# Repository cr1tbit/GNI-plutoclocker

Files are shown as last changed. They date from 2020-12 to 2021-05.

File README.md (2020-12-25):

# GNI-plutoclocker

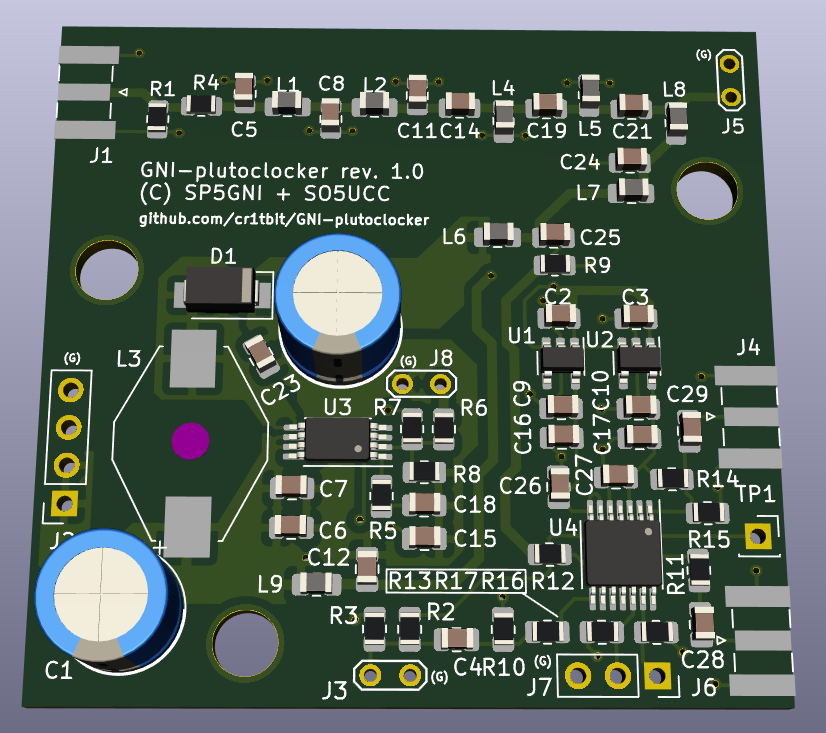
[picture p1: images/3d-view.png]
Board 3d view


This device serves a couple of roles:
* allowing clocking adalm-pluto by an external clock source of broad frequency range
* injecting clock signal into RF trace, for clocking modded LNB
* supplying LNB with DC voltage (12v/18v selectable with an external switch)
* additional clock output

The device is based on CDCE913 which is a neat 3-output clock source generator. It has an excillent, low jitter PLL inside, and has been tested to work well with an OCXO for the purpose of communication via OSCAR-100 satellite.

## Configuration

The device is programmed via I2C rail. The proper register values may be programmed, using an arduino sketch ( available in this repo).

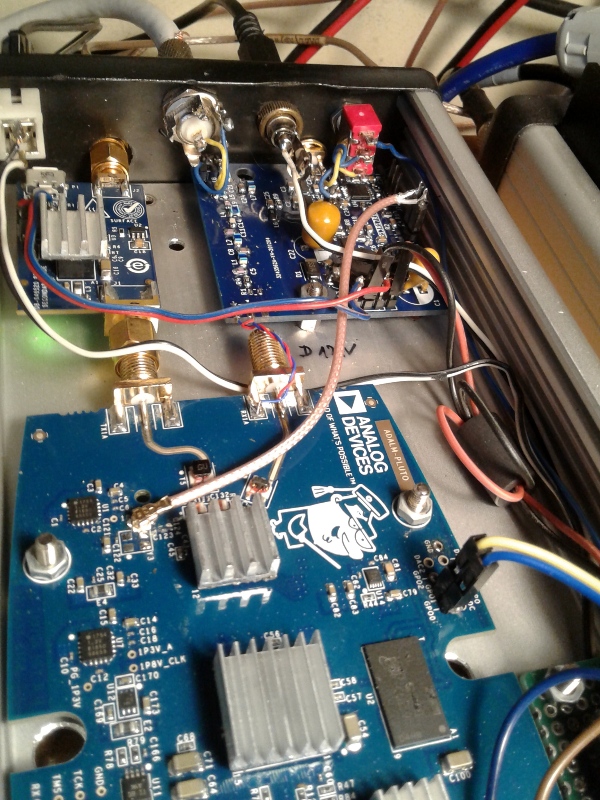
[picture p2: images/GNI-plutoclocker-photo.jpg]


More about this project may be found on https://hf5l.pl/en/adalm-pluto-clocker-2/

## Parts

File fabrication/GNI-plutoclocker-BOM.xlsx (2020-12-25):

Ref | Qnty | Value | Footprint
C1; | 1 | 100u/16V tantalum | Capacitor_THT:CP_Radial_D8.0mm_P3.80mm
C2; C3; C6; C16; C17; | 5 | 10u | Capacitor_SMD:C_0805_2012Metric
C4; C25; C28; C29; | 4 | 10n | Capacitor_SMD:C_0805_2012Metric
C5; C11; | 2 | 5p6 | Capacitor_SMD:C_0805_2012Metric
C7; | 1 | 1u | Capacitor_SMD:C_0805_2012Metric
C8; | 1 | 8p2 | Capacitor_SMD:C_0805_2012Metric
C9; C10; C12; C15; C23; C26; C27; | 7 | 100n | Capacitor_SMD:C_0805_2012Metric
C14; C21; | 2 | 2p7 | Capacitor_SMD:C_0805_2012Metric
C18; | 1 | 1n | Capacitor_SMD:C_0805_2012Metric
C19; | 1 | 1p2 | Capacitor_SMD:C_0805_2012Metric
C22; | 1 | 22u/25v tantalum | Capacitor_THT:CP_Radial_D8.0mm_P3.80mm
C24; | 1 | 68p | Capacitor_SMD:C_0805_2012Metric
D1; | 1 | D_Schottky 20V/1A | Diode_SMD:D_SMA
J1; | 1 | PLUTO_RF_IN | Connector_Coaxial:SMA_EdgeMount male
J2; | 1 | PLUTO_5V | Connector_PinSocket_1x04_P2.54mm_Vertical
J4; | 1 | 10MHZ_IN | Connector_Coaxial:SMA_EdgeMount female
J7; | 1 | I2C_PROG | Connector_PinSocket_1x03_P2.54mm_Vertical
J8; | 1 | 18V_ENA | Connector_PinSocket_1x02_P2.54mm_Vertical
L1; L2; | 2 | 15nH | Inductor_SMD:L_0805_2012Metric_Pad1.15x1.40mm
L3; | 1 | 6.8uH | Inductor_SMD:L_Fastron_PISN_Handsoldering
L4; L5; | 2 | 10nH | Inductor_SMD:L_0805_2012Metric_Pad1.15x1.40mm
L6; L9; | 2 | 2.2uH | Inductor_SMD:L_0805_2012Metric_Pad1.15x1.40mm
L7; L8; | 2 | 100nH | Inductor_SMD:L_0805_2012Metric_Pad1.15x1.40mm
R1; | 1 | 68 | Resistor_SMD:R_0805_2012Metric
R2; R3; R16; R17; | 4 | DNP | Resistor_SMD:R_0805_2012Metric
R4; | 1 | 220 | Resistor_SMD:R_0805_2012Metric
R5; R6; | 2 | 56k | Resistor_SMD:R_0805_2012Metric
R7; | 1 | 240k | Resistor_SMD:R_0805_2012Metric
R8; | 1 | 27k | Resistor_SMD:R_0805_2012Metric
R9; R10; | 2 | 100 | Resistor_SMD:R_0805_2012Metric
R11; R12; R13; | 3 | 22 | Resistor_SMD:R_0805_2012Metric
R14; R15; | 2 | 1k | Resistor_SMD:R_0805_2012Metric
U1; | 1 | MIC5504-3.3YM5 | Package_TO_SOT_SMD:SOT-23-5
U2; | 1 | MIC5504-1.8YM5 | Package_TO_SOT_SMD:SOT-23-5
U3; | 1 | TPS61085 | Package_SO:TSSOP-8_4.4x3mm_P0.65mm
U4; | 1 | CDCE913 | Package_SO:TSSOP-14_4.4x5mm_P0.65mm

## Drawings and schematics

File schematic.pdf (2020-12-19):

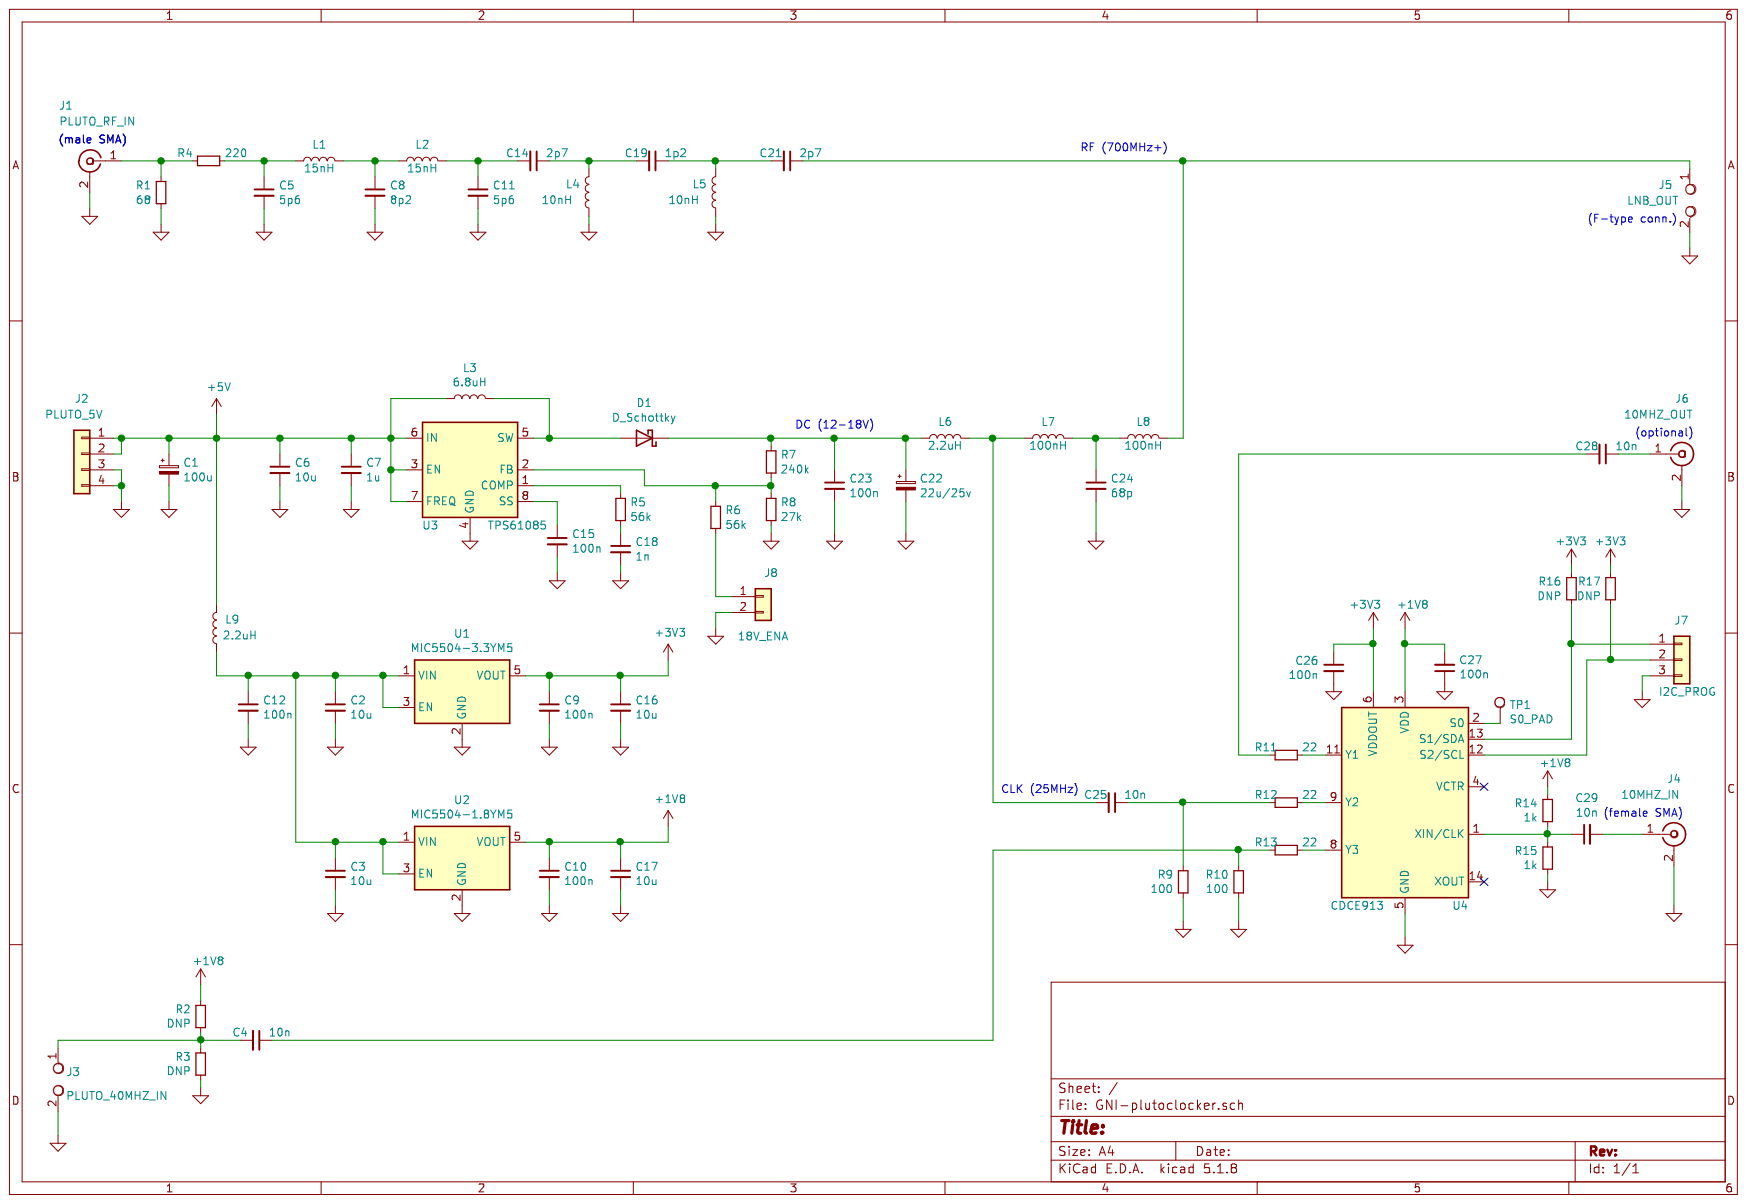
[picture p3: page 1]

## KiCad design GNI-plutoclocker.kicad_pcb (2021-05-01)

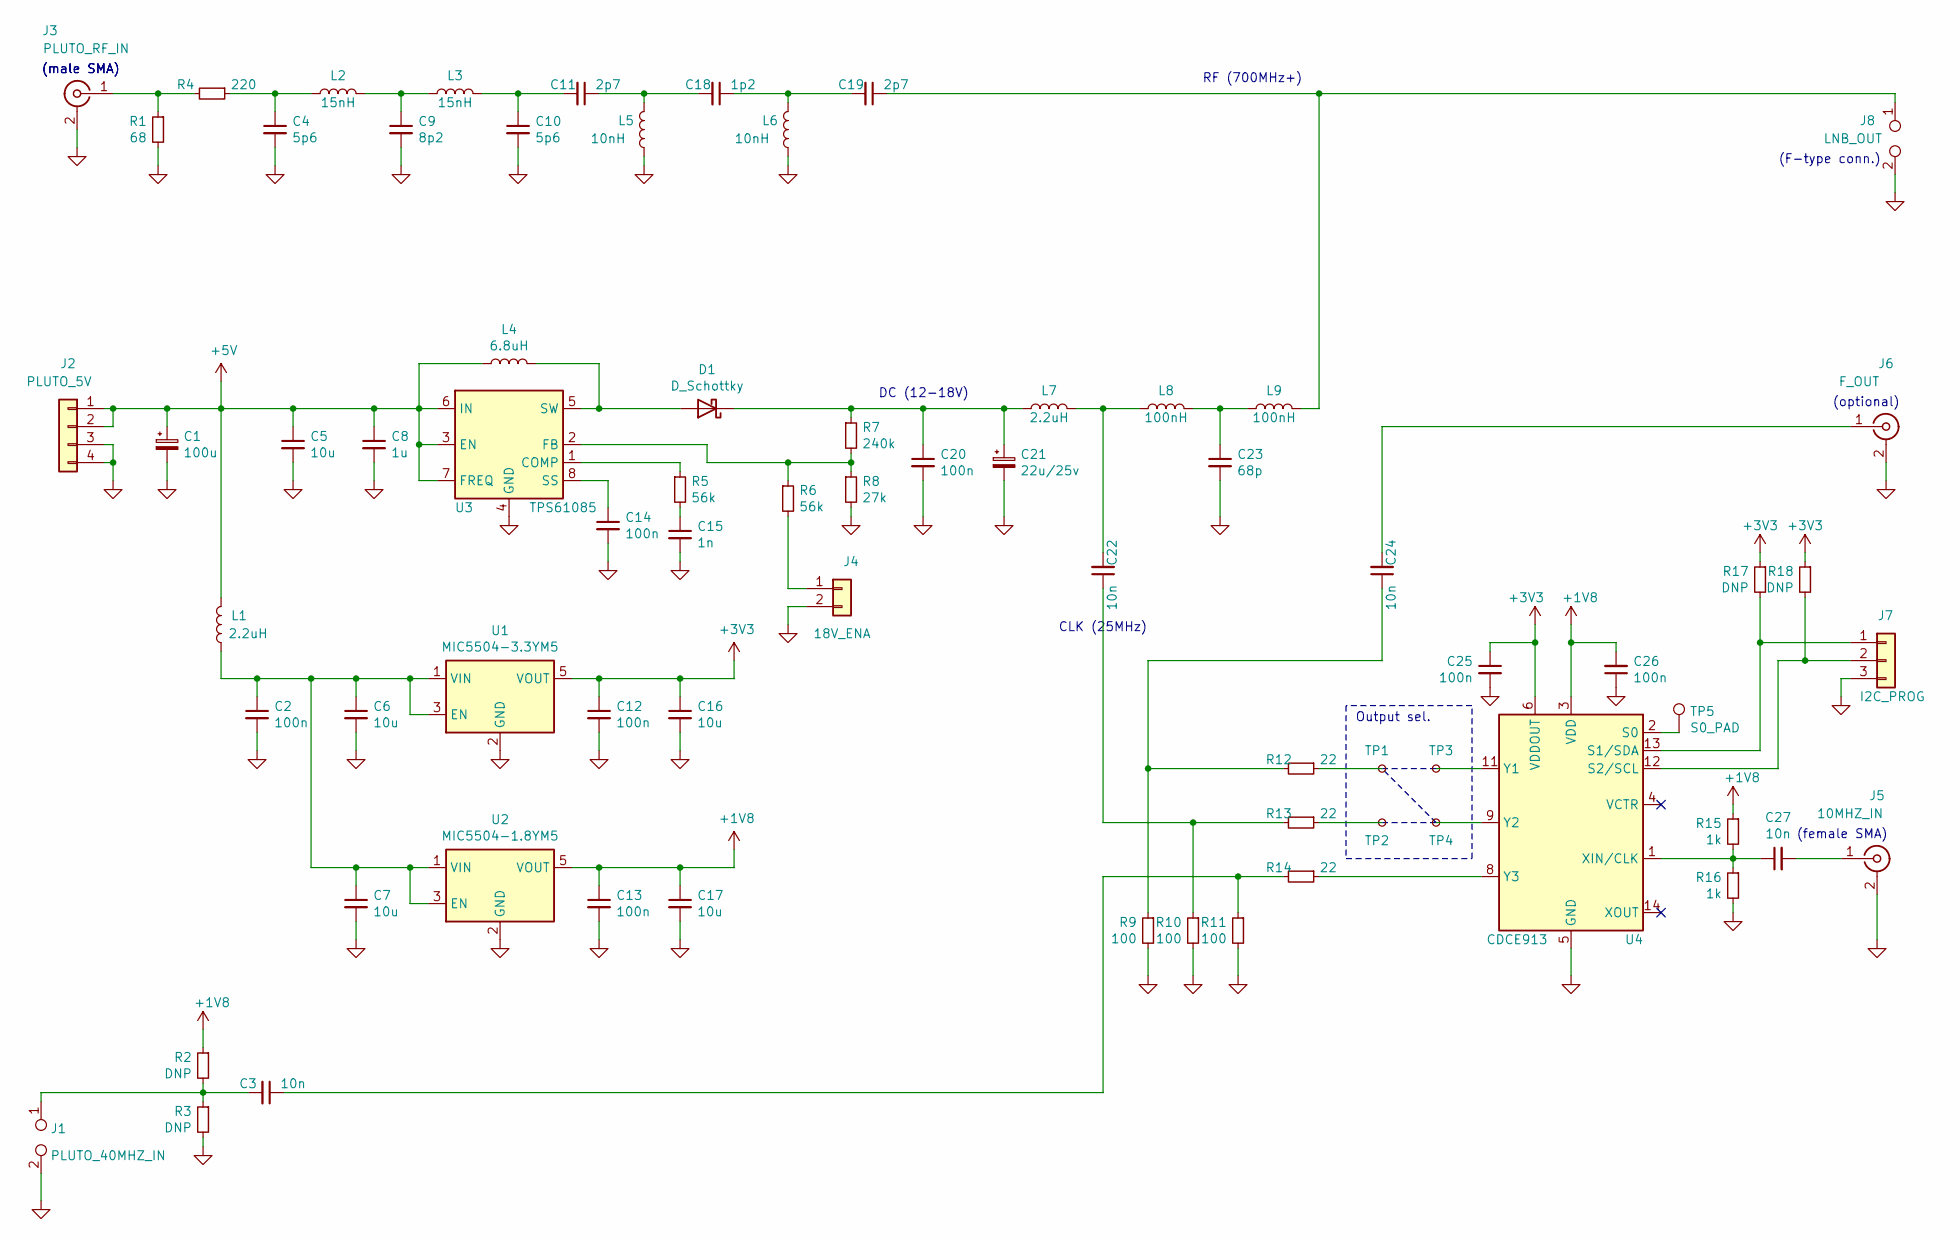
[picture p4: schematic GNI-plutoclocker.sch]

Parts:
C1: 100u; CP_Radial_D8.0mm_P3.80mm
C2, C12, C13, C14, C20, C25, C26: 100n; C_0805_2012Metric
C3, C22, C24, C27: 10n; C_0805_2012Metric
C4, C10: 5p6; C_0805_2012Metric
C5, C6, C7, C16, C17: 10u; C_0805_2012Metric
C8: 1u; C_0805_2012Metric
C9: 8p2; C_0805_2012Metric
C11, C19: 2p7; C_0805_2012Metric
C15: 1n; C_0805_2012Metric
C18: 1p2; C_0805_2012Metric
C21: 22u/25v; CP_Radial_D8.0mm_P3.80mm
C23: 68p; C_0805_2012Metric
D1: D_Schottky; D_SMA
J1: PLUTO_40MHZ_IN; TestPoint_2Pads_Pitch2.54mm_Drill0.8mm
J2: PLUTO_5V; PinSocket_1x04_P2.54mm_Vertical
J3: PLUTO_RF_IN; SMA_Samtec_SMA-J-P-X-ST-EM1_EdgeMount
J4: 18V_ENA; TestPoint_2Pads_Pitch2.54mm_Drill0.8mm
J5: 10MHZ_IN; SMA_Samtec_SMA-J-P-X-ST-EM1_EdgeMount
J6: F_OUT; SMA_Samtec_SMA-J-P-X-ST-EM1_EdgeMount
J7: I2C_PROG; PinSocket_1x03_P2.54mm_Vertical
J8: LNB_OUT; TestPoint_2Pads_Pitch2.54mm_Drill0.8mm
L1, L7: 2.2uH; L_0805_2012Metric_Pad1.15x1.40mm_HandSolder
L2, L3: 15nH; L_0805_2012Metric_Pad1.15x1.40mm_HandSolder
L4: 6.8uH; L_Fastron_PISN_Handsoldering
L5, L6: 10nH; L_0805_2012Metric_Pad1.15x1.40mm_HandSolder
L8, L9: 100nH; L_0805_2012Metric_Pad1.15x1.40mm_HandSolder
R1: 68; R_0805_2012Metric
R2, R3, R17, R18: DNP; R_0805_2012Metric
R4: 220; R_0805_2012Metric
R5, R6: 56k; R_0805_2012Metric
R7: 240k; R_0805_2012Metric
R8: 27k; R_0805_2012Metric
R9, R10, R11: 100; R_0805_2012Metric
R12, R13, R14: 22; R_0805_2012Metric
R15, R16: 1k; R_0805_2012Metric
TP1, TP2, TP3, TP4: TestPoint_Small; TestPoint_Pad_D1.0mm
TP5: S0_PAD; TestPoint_Pad_D1.0mm
U1: MIC5504-3.3YM5; SOT-23-5
U2: MIC5504-1.8YM5; SOT-23-5
U3: TPS61085; TSSOP-8_4.4x3mm_P0.65mm
U4: CDCE913; TSSOP-14_4.4x5mm_P0.65mm

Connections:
+1V8: C13.1, C17.1, C26.2, R2.1, R15.1, U2.5 (VOUT), U4.3 (VDD)
+3V3: C12.1, C16.1, C25.1, R17.1, R18.1, U1.5 (VOUT), U4.6 (VDDOUT), U4.7 (VDDOUT)
+5V: C1.1, C5.1, C8.1, J2.1, J2.2, L1.2, L4.1, U3.3 (EN), U3.6 (IN), U3.7 (FREQ)
GND: C1.2, C2.2, C4.2, C5.2, C6.2, C7.2, C8.2, C9.2, C10.2, C12.2, C13.2, C14.2, C15.2, C16.2, C17.2, C20.2, C21.2, C23.2, C25.2, C26.1, J1.2, J2.3, J2.4, J3.2 (Ext), J4.2, J5.2 (Ext), J6.2 (Ext), J7.3, J8.2, L5.1, L6.1, R1.2, R3.2, R8.2, R9.2, R10.2, R11.2, R16.2, U1.2 (GND), U2.2 (GND), U3.4 (GND), U4.5 (GND), U4.10 (GND)
unnamed: C2.1, C6.1, C7.1, L1.1, U1.1 (VIN), U1.3 (EN), U2.1 (VIN), U2.3 (EN)
unnamed: C3.1, R11.1, R14.2
unnamed: C3.2, J1.1, R2.2, R3.1
unnamed: C4.1, L2.1, R4.1
unnamed: C9.1, L2.2, L3.1
unnamed: C10.1, C11.2, L3.2
unnamed: C11.1, C18.2, L5.2
unnamed: C14.1, U3.8 (SS)
unnamed: C15.1, R5.2
unnamed: C18.1, C19.2, L6.2
unnamed: C19.1, J8.1, L9.2
unnamed: C20.1, C21.1, D1.1 (K), L7.1, R7.1
unnamed: C22.1, R10.1, R13.2
unnamed: C22.2, L7.2, L8.1
unnamed: C23.1, L8.2, L9.1
unnamed: C24.1, R9.1, R12.2
unnamed: C24.2, J6.1 (In)
unnamed: C27.1, R15.2, R16.1, U4.1 (XIN/CLK)
unnamed: C27.2, J5.1 (In)
unnamed: D1.2 (A), L4.2, U3.5 (SW)
unnamed: J3.1 (In), R1.1, R4.2
unnamed: J4.1, R6.2
unnamed: J7.1, R17.2, U4.13 (S1/SDA)
unnamed: J7.2, R18.2, U4.12 (S2/SCL)
unnamed: R5.1, U3.1 (COMP)
unnamed: R6.1, R7.2, R8.1, U3.2 (FB)
unnamed: R12.1, TP1.1
unnamed: R13.1, TP2.1
unnamed: R14.1, U4.8 (Y3)
unnamed: TP3.1, U4.11 (Y1)
unnamed: TP4.1, U4.9 (Y2)
unnamed: TP5.1, U4.2 (S0)

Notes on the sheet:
RF (700MHz+)
DC (12-18V)
CLK (25MHz)
(male SMA)
(F-type conn.)
(female SMA)
(optional)
Output sel.

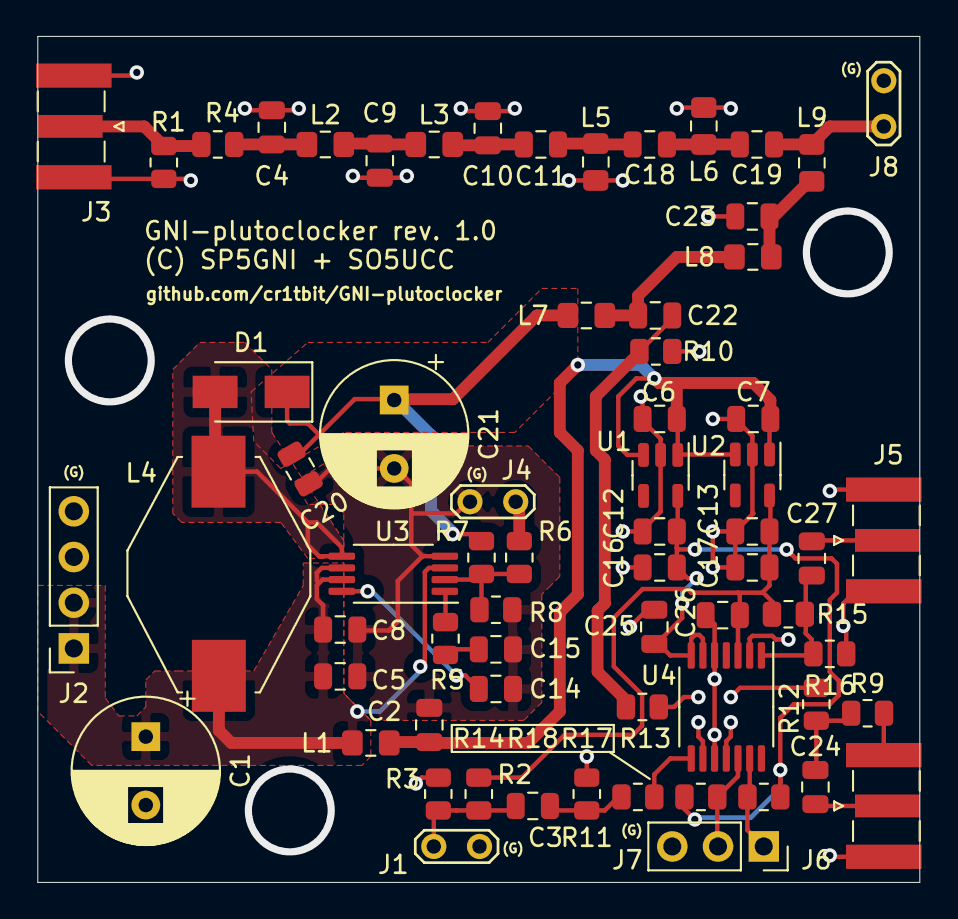
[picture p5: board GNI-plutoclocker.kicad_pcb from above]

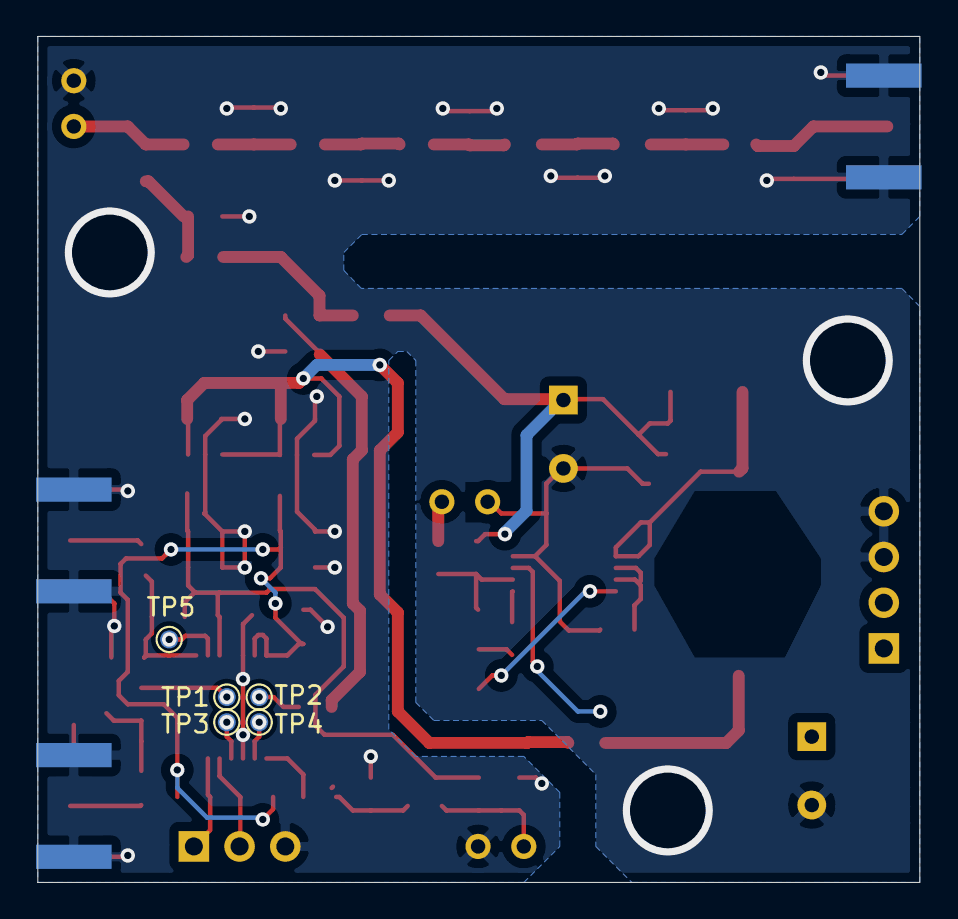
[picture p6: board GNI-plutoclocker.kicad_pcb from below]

Board: 2 copper layers, 49.0 x 47.0 mm, 72 parts (5 on the bottom side), 36 nets.

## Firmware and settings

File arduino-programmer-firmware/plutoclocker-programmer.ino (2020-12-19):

/*  CDCE913 programmer code for Arduino
  ========================================================
  Intended for programing CDCE913 as 25 MHz clock reference for LNB and 40 MHz for ADALM Pluto
  
  Ver. 0.5

Copyright (c) 2020 Mirosław Sadowski, Jakub Sadowski

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
THE SOFTWARE IS PROVIDED "AS IS", WITHOUT WARRANTY OF ANY KIND, EXPRESS 
OR IMPLIED, INCLUDING BUT NOT LIMITED TO THE WARRANTIES OF MERCHANTABILITY, 
FITNESS FOR A PARTICULAR PURPOSE AND NONINFRINGEMENT. IN NO EVENT SHALL THE 
AUTHORS OR COPYRIGHT HOLDERS BE LIABLE FOR ANY CLAIM, DAMAGES OR OTHER LIABILITY, 
WHETHER IN AN ACTION OF CONTRACT, TORT OR OTHERWISE, ARISING FROM, OUT OF OR 
IN CONNECTION WITH THE SOFTWARE OR THE USE OR OTHER DEALINGS IN THE SOFTWARE.
*/
  
#include <Wire.h>

void setup() {
  pinMode(LED_BUILTIN, OUTPUT);
  
  Wire.begin();

  // 4 MHz generator may be used for debug purposes - uncomment the line below
  // setup_4MHZ_clk();
  
  program_CDCE913();
}

void loop() {
  digitalWrite(LED_BUILTIN, HIGH); 
  delay(750);
  digitalWrite(LED_BUILTIN, LOW);
  delay(250);
}


void setup_4MHZ_clk(){
  pinMode(11,OUTPUT);
  
  TCCR2A = ((1 << WGM21) | (1 << COM2A0));
  TCCR2B = (1 << CS20); // prescaler = 1
  TIMSK2 = 0;
  OCR2A = 1;
}

void program_CDCE913(){
  /*
   * Based on http://sp9uob.verox.pl/pliki/fiberref.pdf
   * 
   * These example values enable Y1=10, Y2=25 and Y3=40 MHz outputs, when 10 MHz CLK nput is connected.
   */
  
  uint8_t addr = 0x65;
  uint8_t comm1[7] = {
    0x01, 0x06, 0x05, 0x34, 0x01, 0x02, 0x50
  };
  uint8_t comm2[14] = {
    0x14, 0x0c, 0x6D, 0x02, 0x08, 0x05, 0xff,
    0x00, 0x02, 0x83, 0xff, 0x00, 0x02, 0x80
  };
  uint8_t comm_save_eeprom[2] = {0x86, 0x01};

  Wire.beginTransmission(addr);
  Wire.write(comm1,7);
  Wire.endTransmission();

  delay(100);
  
  Wire.beginTransmission(addr);
  Wire.write(comm2,14);
  Wire.endTransmission();

  delay(100);

  Wire.beginTransmission(addr);
  Wire.write(comm_save_eeprom,2);
  Wire.endTransmission();
}

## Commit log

2020-11-24 adding PDF schematic
2020-12-16 adding some project changes and fab outputs
    [GNI-plutoclocker-B_Cu.gbr, GNI-plutoclocker-B_Mask.gbr, GNI-plutoclocker-B_Paste.gbr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]
2020-12-19 minor aesthetics schematics and silk layer adjustments
    [GNI-plutoclocker-B_Cu.gbr, GNI-plutoclocker-B_Mask.gbr, GNI-plutoclocker-B_Paste.gbr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]
2020-12-19 adding 3d view image
    [GNI-plutoclocker.kicad_pcb]
2020-12-25 adding BOM file
    [GNI-plutoclocker-BOM.xlsx]
2021-05-01 next revision candidate - adding some solderbridge multiplexing options
    [GNI-plutoclocker.kicad_pcb, GNI-plutoclocker.sch]
